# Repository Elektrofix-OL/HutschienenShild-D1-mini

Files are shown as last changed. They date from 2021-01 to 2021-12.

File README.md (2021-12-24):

# HutschienenShild-D1-mini
Wemos D1 direkt in Verteilung incl. Spannungsversorgung 5V nutzen

Nach dem die App von meinem Energieversorger versagte, wollte ich meinen Haupt- und Zwischenzähler per S0 bzw. D0 auslesen können und die Daten Speicher können.
Bei Youtube konnte ich dann erfahren, wie die Daten auf einen Raspberry gespeichert, ausgewertet und angezeigt werden können. Was fehlte war die Möglichkeit einen ESP8266 direkt auf die Hutschiene zu setzten und nur noch anzuschießen.
Darum habe ich mich rangesetzt, ein Shield zu entwikeln.

# Schaltplan:
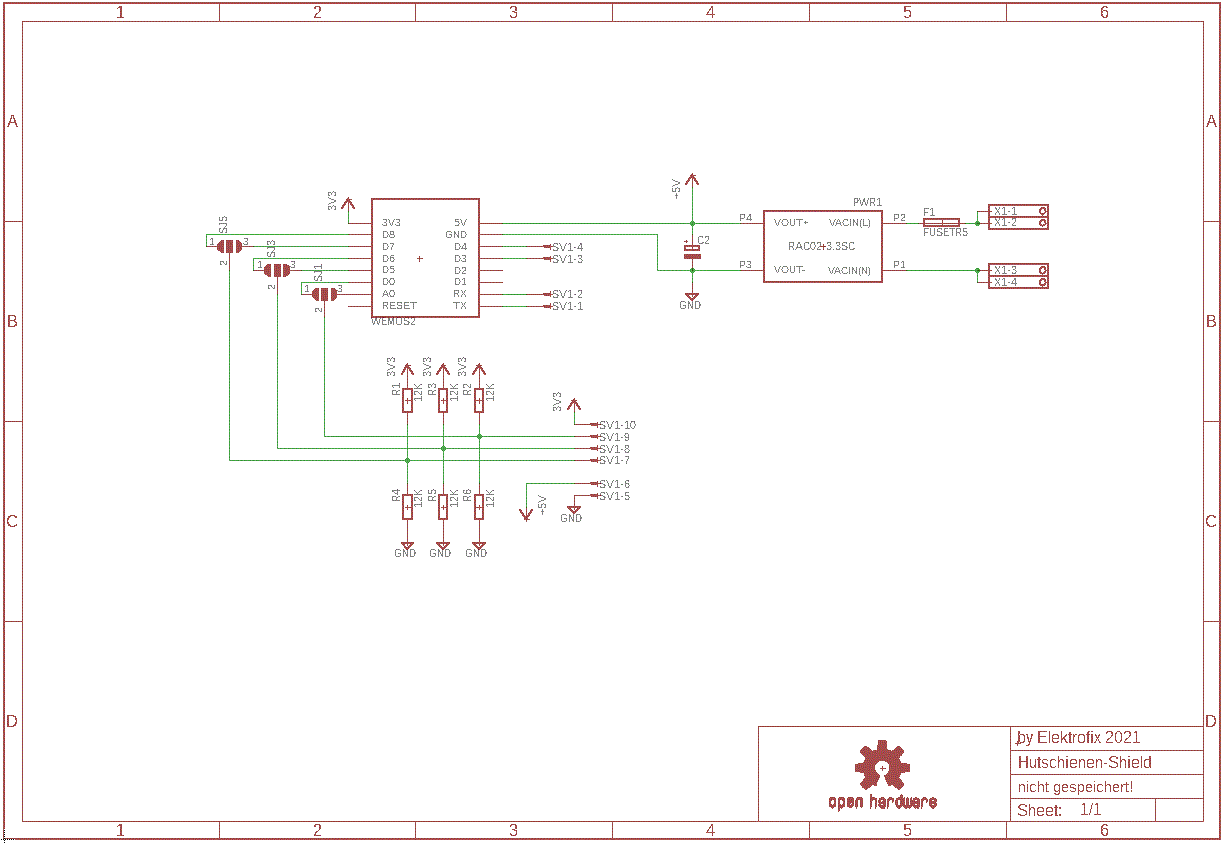
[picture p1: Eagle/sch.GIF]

Wie zu sehen ist, ist das ganze nicht's besonderes. Aus 230V-AC werden über ein Wandler 5V-DC bereitgestellt. Der D1-Mini macht daraus seinen 3,3V und die Ein-/Ausgänge werden direkt an SV1 herausgeführt.
Auf der Leiterplatte sind für die Anschlüsse SV1-7 bis SV1-9 Pullup- und Pulldown-Widerstände möglich, wobei dort natürlich auch einen Freilaufdiode eingelötet werden können.
Auf der Unterseite sind Lötbrücken vorgesehen. So kann jeder selber entscheiden, welcher GPio von nutzen ist, da einige GPio's beim Booten des D1-Mini eine bestimmten Pegel haben müssen. Mit diesen Brücken können somit 5 digitale, oder 4 digitale und der analogen GPio's genutzt werden.
Am SV1 sind außer die 5 GPio-Zugänge noch Tx, Rx, +5V, +3,3V und GND erausgeführt. Ferne ist es möglich noch im Gehäuse ein weiteres Shild unterzubringen (sieh Foto's) 

# Gehäuse-Bilder
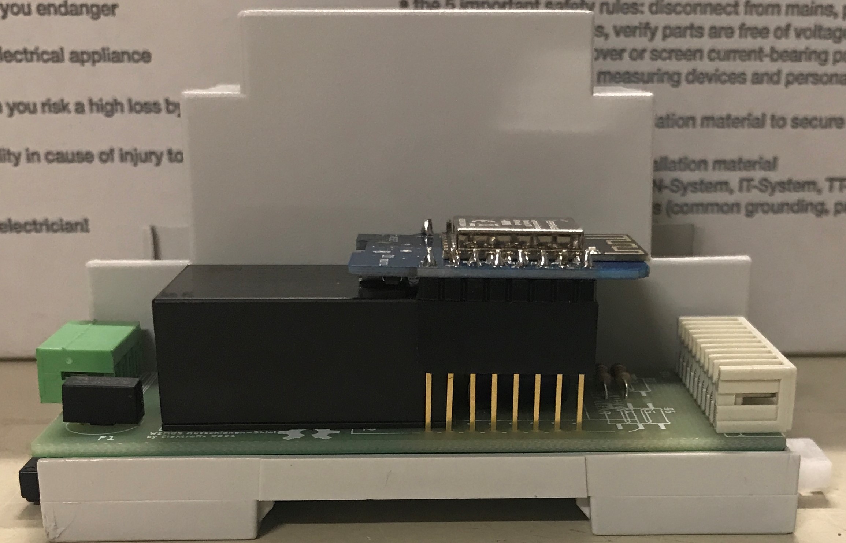
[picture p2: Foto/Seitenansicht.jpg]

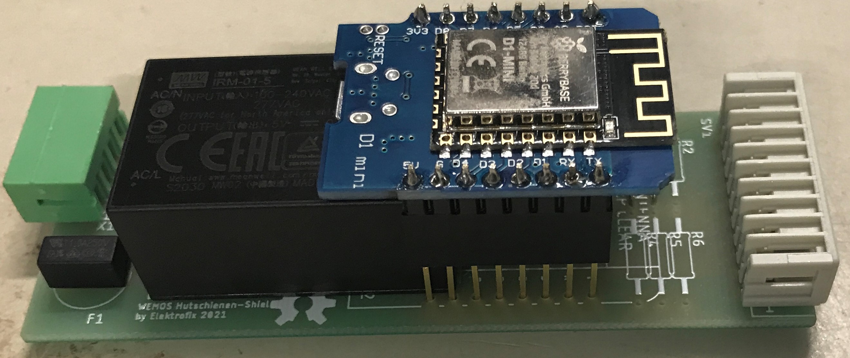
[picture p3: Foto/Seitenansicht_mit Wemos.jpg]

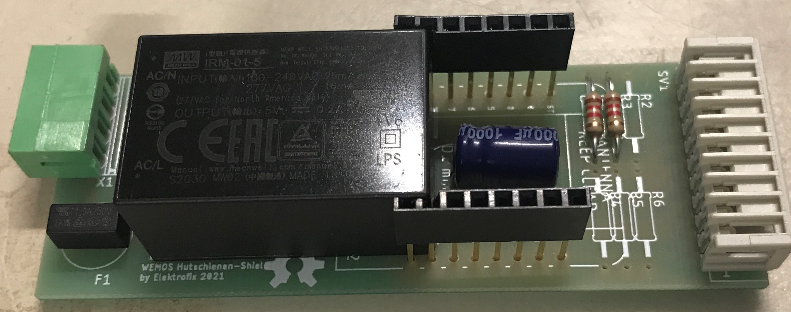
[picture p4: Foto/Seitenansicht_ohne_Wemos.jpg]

Wie zu sehen ist, passen die Kontakthalten nicht ganz, daher haben ich mit einem Cutter die beinden letzten Kontakthalter halbiert. Der elekrische Kontakt wird nicht beeinträchtigt.
Der Kondensator kann auch größer gewählt werden, bei mir dient er als Glättung, damit die Schaltung nicht ins Schwingen kommt.

# Bauteile
für die Bauteile habe ich eine Liste bei [www.reichelt.de](https://www.reichelt.de/my/1790195) erstellt. 

# Lizenz
Copyright (c) 2021 Elektrofix

Jeder Mensch darf das Projekt benutzen, kopieren und verändern. Der Verkauf ist jedoch verboten und auch nach der Veränderung dürfen Teile des Projekten nicht veräußert werden. Ihr habt es kostenlos bekommt, also müsst ihr die Änderungen auch Kostenlos weitergeben! Geld machen mit meinen Ideen ist nicht!

Der obige Urheberrechtshinweis und dieser Genehmigungshinweis müssen in alle Kopien oder wesentlichen Teile der Software aufgenommen werden.

Alles macht ihr aus eigenes Risiko, Haftung und Gewährleistung über nehme ich keine.

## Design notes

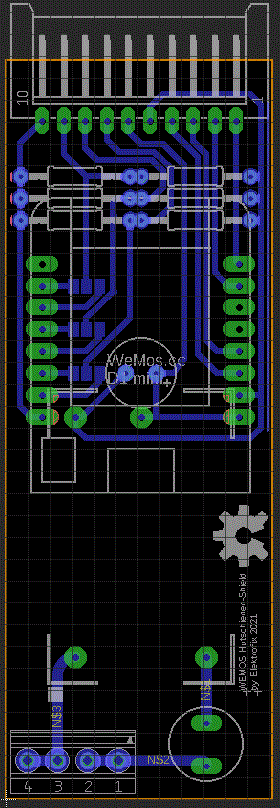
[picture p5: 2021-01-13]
Eagle/BRD.GIF

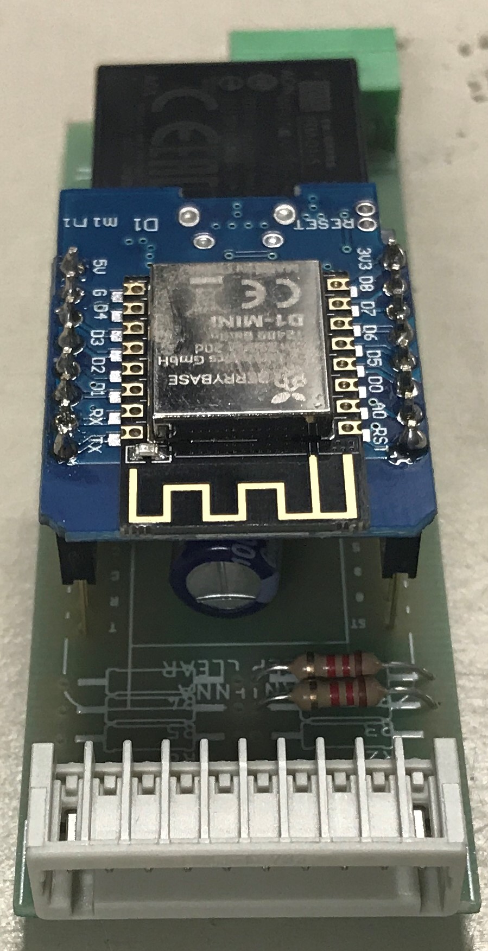
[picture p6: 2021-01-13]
Foto/Frontansicht.jpg

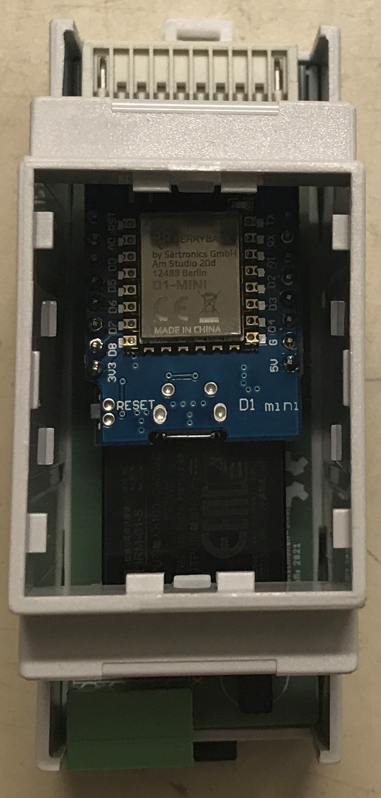
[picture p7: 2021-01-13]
Foto/Innenansicht.jpg

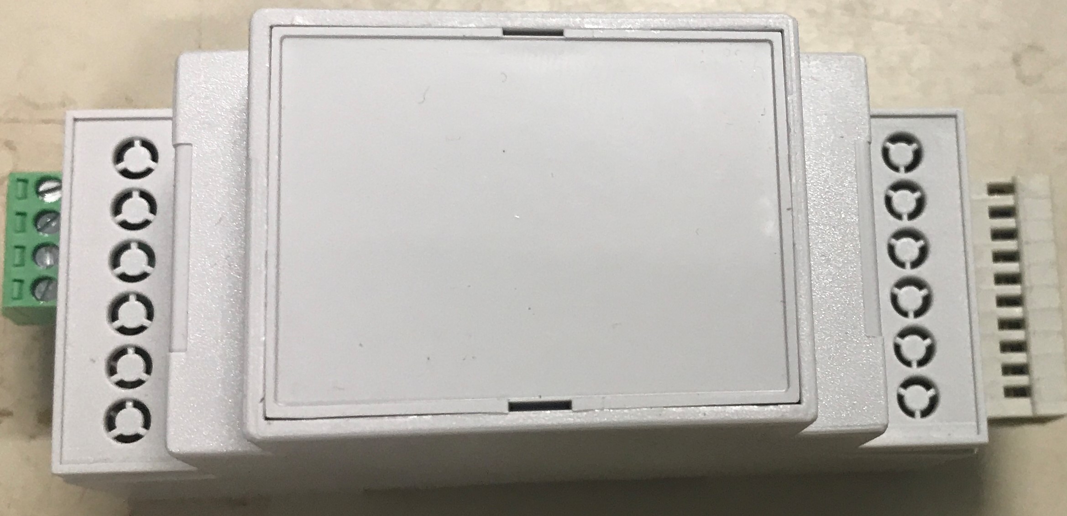
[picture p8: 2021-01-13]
Foto/Draufsicht.jpg

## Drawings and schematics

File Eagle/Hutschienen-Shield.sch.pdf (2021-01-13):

A

A

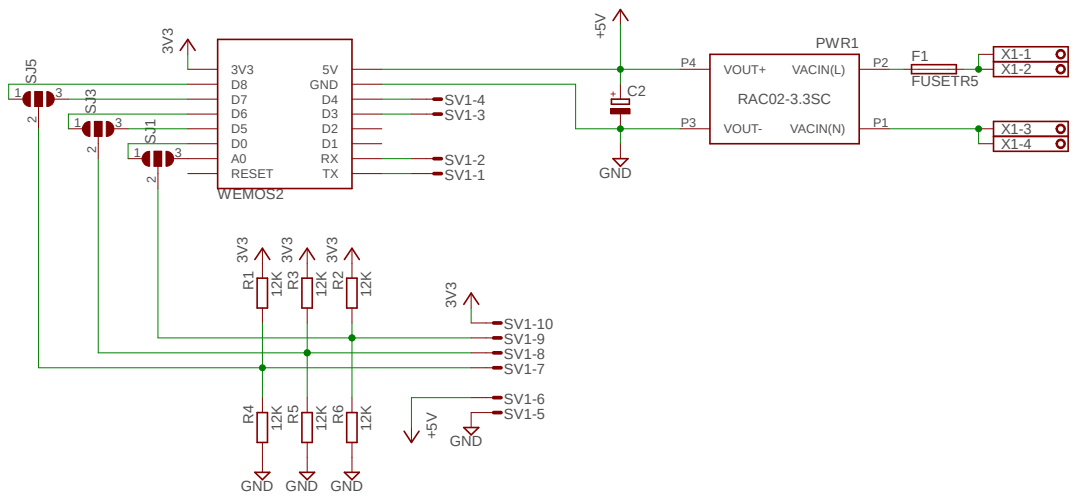
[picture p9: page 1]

20.12.2020 15:14 f=1.08 C:\Users\KarstenKeller\Nextcloud2\Projekte\Hutschienen-Shield\Hutschienen-Shield.sch (Sheet: 1/1) ³V³

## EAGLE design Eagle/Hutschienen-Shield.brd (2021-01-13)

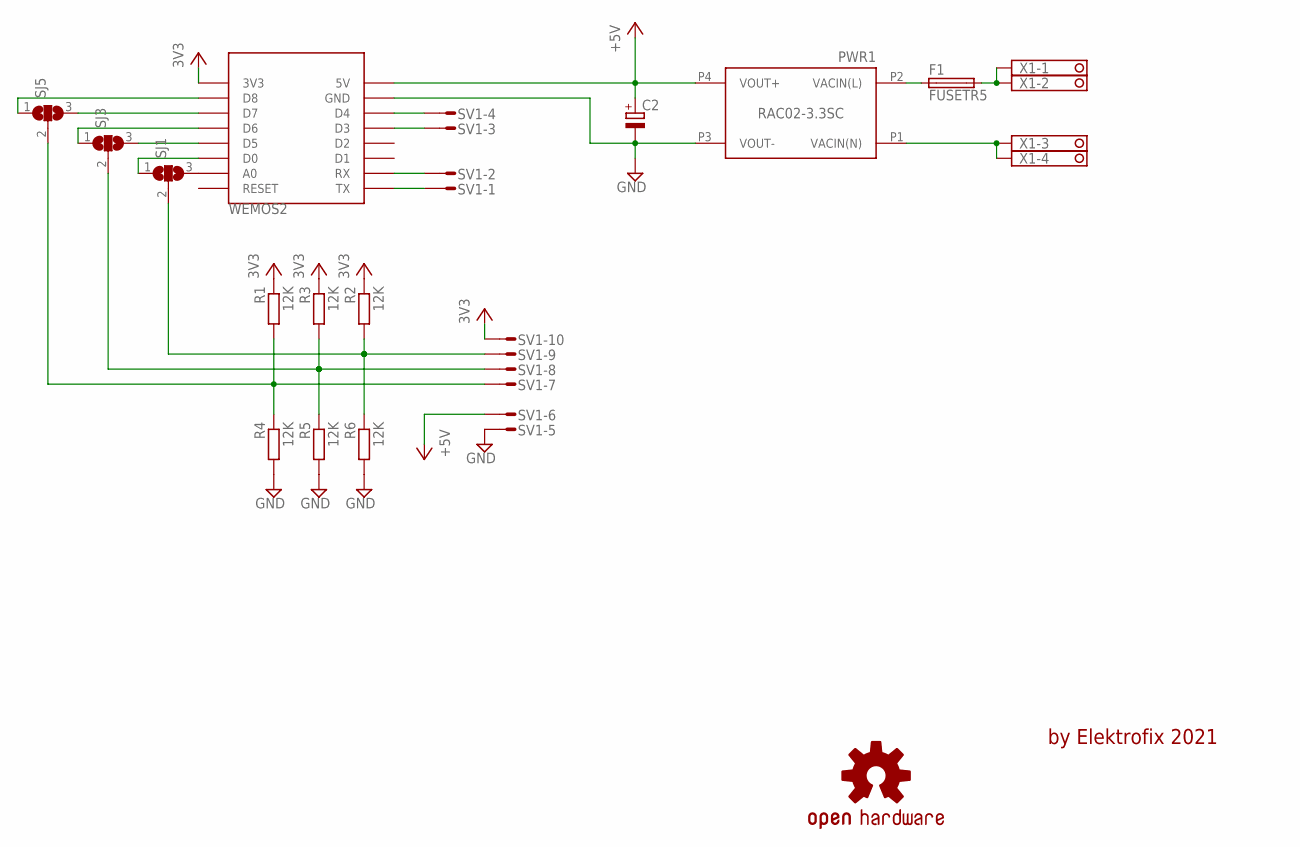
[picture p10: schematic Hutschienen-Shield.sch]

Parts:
C2: CPOL-EUE3.5-8; E3,5-8
F1: FUSETR5; TR5
LOGO1: OSHW-LOGOL; OSHW-LOGO-L
PWR1: RAC02-3.3SC; LOW_PROFILE_POWER_MODULE
R1, R2, R3, R4, R5, R6: 12K; 0207/12
SJ1, SJ3, SJ5: SJ2W; SJ_2
SV1: L10P
WEMOS2: WEMOS-D1-MINI
X1: 1751264

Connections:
3V3: R1.1, R2.1, R3.1, SV1.10, WEMOS2.3V3
+5V: C2.+, PWR1.P4 (VOUT+), SV1.6, WEMOS2.5V
GND: C2.-, PWR1.P3 (VOUT-), R4.2, R5.2, R6.2, SV1.5, WEMOS2.GND
unnamed: F1.1, PWR1.P2 (VACIN(L))
unnamed: F1.2, X1.1, X1.2
unnamed: PWR1.P1 (VACIN(N)), X1.3, X1.4
unnamed: SV1.4, WEMOS2.D4
unnamed: SV1.3, WEMOS2.D3
unnamed: SV1.1, WEMOS2.TX
unnamed: SV1.2, WEMOS2.RX
unnamed: SJ1.3, WEMOS2.A0
unnamed: SJ1.1, WEMOS2.D0
unnamed: SJ3.3, WEMOS2.D5
unnamed: SJ3.1, WEMOS2.D6
unnamed: SJ5.3, WEMOS2.D7
unnamed: SJ5.1, WEMOS2.D8
unnamed: R2.2, R6.1, SJ1.2, SV1.9
unnamed: R3.2, R5.1, SJ3.2, SV1.8
unnamed: R1.2, R4.1, SJ5.2, SV1.7

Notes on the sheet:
by Elektrofix 2021

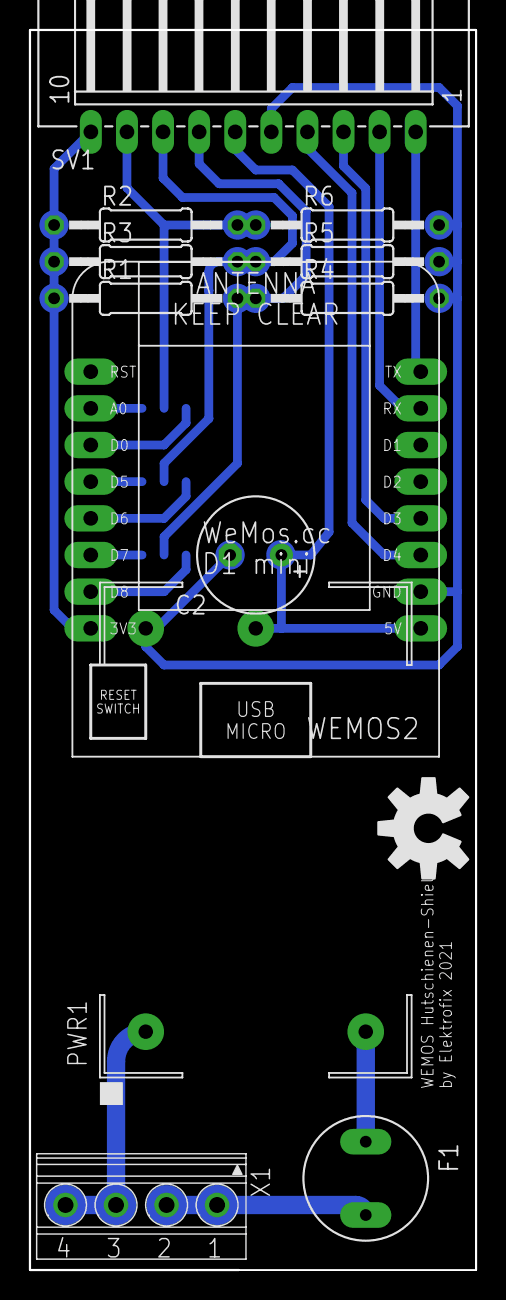
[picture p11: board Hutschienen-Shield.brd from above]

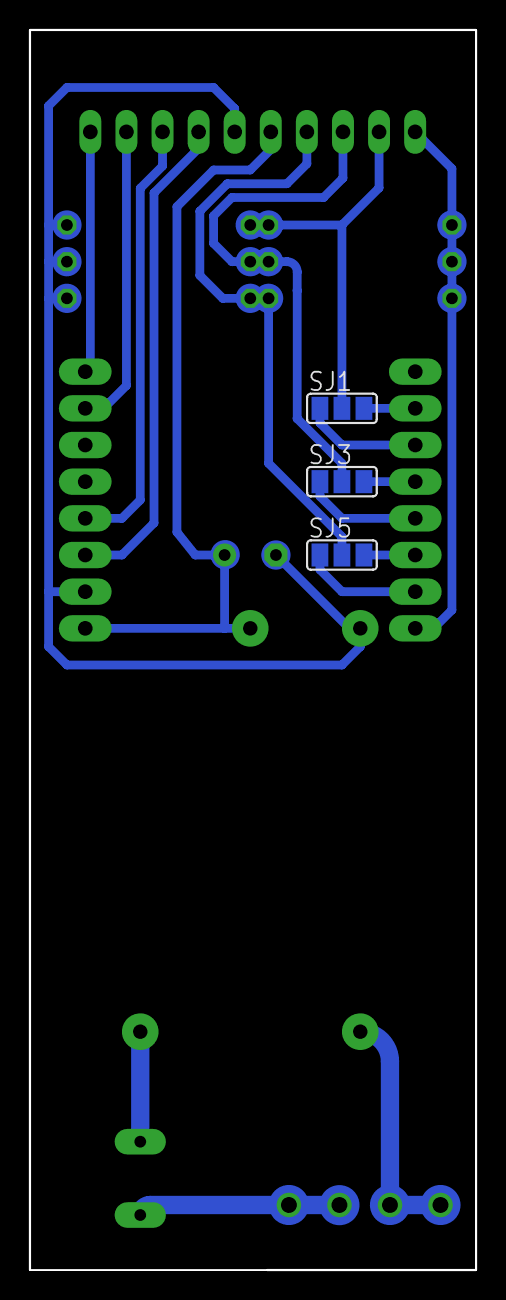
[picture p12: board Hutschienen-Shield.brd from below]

Board: 2 copper layers, 30.9 x 85.9 mm, 16 parts (3 on the bottom side), 19 nets.

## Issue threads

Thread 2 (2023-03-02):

[Question] Platine für M-Bus ?

Noschvie, 2023-03-02:
Hallo Karsten
vielleicht kannst du diese deine Platine abändern / erweitern, um ein M-Bus Interface (SmartMeter) zu realisieren?
[Circuit_Mbus](https://github.com/all4electronics/SmartMeter-Kundenschnittstelle-auslesen/blob/main/Circuit_Mbus.pdf)
Und ein ESP32 D1mini mit Tasmota ...

Elektrofix-OL, 2023-03-02:
Hallo Norbert,

das Shild ist ja so universal aufgebaut, das weiter Shilds draufgesteckt werden können. Ich habe mit noch eines gebaut, welches die Eingänge D3 und D4 vom Wemos (onTOP) auf BC547B bringt und der Kolektor kommt vom D3 und D4 vom unten. Das mit dem ESP32 ist ein guter Tip, aber das mit dem M-Bus sehe ich noch nicht, würde Zuviele Möglichkeiten nehmen, die Eingänge individuell zu beschalten.
Ein Beispiel: Bei mir haben ich je ein HutschienenShild für:
- in Keller für 1xIR-Lesekopf, S0-Zähler, zwei Relais für Rolladensteuerung
- in 1.OG für 4 x S0-Zähler
- in der Garage für 1x So-Zähler, Endschalter Gerage offen, Relais für Garage zu und Garage öffnen
Alles war möglich über die Eingänge und die Signale vom Wemos und Pullup- oder Pulldown-Widerstände

Werde mal schauen, wann die V2 kommt 😉.

Noschvie, 2023-03-02:
In AT ist M-Bus weit verbreitet und oftmals wird ein "ESP M-Bus only" Device verwendet, um den SmartMeter auszulesen und die Daten über MQTT weiterzuleiten... Die Kompaktheit der Platine mit Hutschienengehäuse ist einfach Top !

Elektrofix-OL, 2023-03-02:
Also möchtest Du eine Platine für M-Bus haben, die nicht anderes kann?

Noschvie, 2023-03-02:
Ja genau…

Noschvie, 2023-03-03:
Nachtrag: ESP32 deswegen, weil mehr Resourcen verfügbar und einfacher in der Handhabung mit Tasmota. Wegen der Kompaktheit ESP32 D1mini oder ESP32 C3mini.
Oder ein "nicht Development Board" gleich zum Auflöten mit Pins zum Flashen.
ps: bin kein HW Spezialist...

Elektrofix-OL, 2023-03-03:
Ok, wenn ich das jetzt richtig verstanden haben: Du suchst eine Möglichkeit einen ESP32 als D3 mit einen Mikroe M-Bus Slave in einen HutschienenShild unterzukriegen, damit Du die Zähler in Österreich auslesen kannst.
Und Du bist ein Softi ohne Hardwarekenntnis und suchst jemanden der Dir das baut.

Wenn dem so ist, dann schicke mir mal die Datenblätter von den PCB‘s die Du verwenden möchtest, damit ich schaue, ob diese mechanisch in das Gehäuse passen. Und schaue nach, wo Du günstig im Internet die PCB‘s produzieren lassen kannst. Meine Quelle ist nur für Firmen und ist nicht gerade günstig.

Noschvie, 2023-03-03:
Vom M-Bus wird nur die Empfangsrichtung (TX -> RX (ESP)) benötigt. Es muss nicht das Mikroe M-Bus Slave sein.
Einfacher geht's vermutlich mit der Schaltung im ersten Post. Diese Teile für den M-Bus plus "dein" Teil mit Spannungsversorgung und ESP32. TX vom M-Bus auf RX vom ESP.
Hatte schon mal PCBs online bestellt, erinnere mich aber nicht wo, war für WLED / ESP.

Elektrofix-OL, 2023-03-03:
Es ist aber immer noch die Frage, welches ESP32Board Du verwenden willst. Ich habe kein ESP32 und die muss ja die Pins anderes belegen.

Noschvie, 2023-03-03:
ESP8266 D1mini und ESP32 D1mini NodeMCU sind PIN kompatibel, siehe az-delivery.de, das ist das Gute daran.
https://www.az-delivery.de/products/esp32-d1-mini
https://amzn.eu/d/dsmRMs9
Kann dir auch gerne einen ESP32 D1mini zukommen lassen (zB amazon.de Gutschein).

Elektrofix-OL, 2023-03-06:
Ich muss noch ein paar andere Projekte umsetzten und habe nur noch diese Woche Urlaub; aber danach kann ich mich mal ransetzten. Du musst nur schauen, wo die PCB gefertigt werden können und eine Spezifikation der M-Busschnittstelle wäre gut.

Ich habe da so ein Verdacht als ob das RS485 nur mit einem anderen "Dialekt" ist, so die OBIS und SML.
Ein Schaltplan vom M-Bus Slave hast Du nicht zufällig? Auf dem PCB sehen ich eine galvanische Trennung und die wird nicht umsonst da sein.

Noschvie, 2023-03-06:
https://de.wikipedia.org/wiki/M-Bus_(Feldbus),
[Specifications](https://www.mikroe.com/m-bus-slave-click)
[Schaltplan](https://download.mikroe.com/documents/add-on-boards/click/m-bus_slave_click/m-bus-slave-click-schematic-v100.pdf)

Elektrofix-OL, 2023-03-07:
ich habe mir das heute mal intensiv angeschaut, aber es war ernüchtern. in Eagel habe ich weder den TSS721 noch einen ESP32 gefunden. ich müsste alle diese Eagle erst neu erstelle um dann ein Board zu routen.
Es gibt nur die Lösung, den ESP32 und das M-bus-Slave im Huckepack auf das Hutschienenshild zu setzen.
Neben den mechanischen Problemchen müsstest Du schauen, ob Du beim ESP32 jeden IOPin als TX und RX nehmen kannst und ob die beiden PCB's übereinandern passen.
Ich habe noch PCB von HutschienenShild da, eines sogar mit Netzteil.

Noschvie, 2023-03-13:
Hallo Karsten, nochmals danke für deine Zeit.

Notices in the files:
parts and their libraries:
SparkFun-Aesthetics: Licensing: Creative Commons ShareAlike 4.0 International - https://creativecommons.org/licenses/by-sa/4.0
